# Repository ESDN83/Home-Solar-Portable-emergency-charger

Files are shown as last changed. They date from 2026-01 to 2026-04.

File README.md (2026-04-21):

<div align="center">

# ⚡ Home Solar Portable Emergency Charger 

**[🖼️ Bilder/Pictures](documentation/images.md)**

### Notstrom-Ladegerät für PV-Heimspeicher mittels Generator
### Emergency Charger for PV Home Battery Systems using Generator






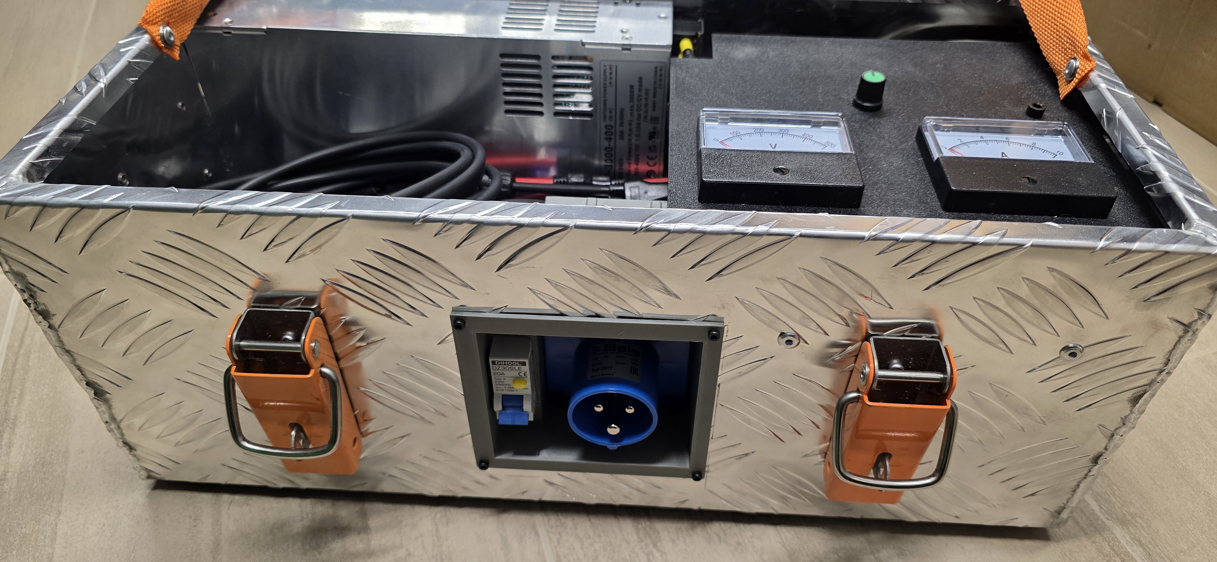
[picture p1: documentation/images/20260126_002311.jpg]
Project Photos


**[🇩🇪 Deutsch](#-deutsch)** | **[🇬🇧 English](#-english)**

</div>

---

## 📋 Table of Contents / Inhaltsverzeichnis

- [🇩🇪 Deutsch](#-deutsch)
  - [Überblick](#überblick)
  - [Das Problem](#das-problem)
  - [Die Lösung](#die-lösung)
  - [Hauptkomponenten](#-hauptkomponenten)
  - [Dokumentation](#-dokumentation)
- [🇬🇧 English](#-english)
  - [Overview](#overview)
  - [The Problem](#the-problem)
  - [The Solution](#the-solution)
  - [Main Components](#-main-components)
  - [Documentation](#-documentation)
- [⚠️ Safety / Sicherheit](#%EF%B8%8F-safety--sicherheit)
- [📚 References / Referenzen](#-references--referenzen)
- [📄 License / Lizenz](#-license--lizenz)

---

## 🇩🇪 Deutsch

### Überblick

Dieses Open-Source-Projekt beschreibt den Bau eines **portablen Notstrom-Ladegeräts** für PV-Heimspeicher-Systeme (E3/DC, Fronius, SMA, etc.). Das System ermöglicht es, einen handelsüblichen Generator zur Ladung des Hausspeichers zu nutzen, wenn das Stromnetz ausfällt.

### Das Problem

Viele moderne Heimspeicher-Systeme (wie E3/DC) verweigern das direkte Laden der Batterie über einen Generator am AC-Eingang aufgrund von:
- 🔴 Frequenzinstabilitäten des Generators
- 🔴 Netzqualität entspricht nicht den Anforderungen
- 🔴 Fehlende Grid-Code-Konformität

### Die Lösung

Statt den Generator direkt ans Hausnetz anzuschließen, nutzen wir einen **alternativen Ansatz**:

```
Generator (230V AC) 
    ↓
MeanWell CSP-3000-400 Netzteil
    ↓
DC-Spannung (350-400V, bis 7.5A)
    ↓
Sperrdioden (Anti-Backfeed)
    ↓
PV-Eingang (MPPT) des Wechselrichters
    ↓
Batterie wird geladen ✅
```

Das System **simuliert eine Solaranlage** und speist DC-Strom direkt in die MPPT-Tracker ein, wodurch der Heimspeicher geladen wird!

### 🔧 Hauptkomponenten

| Komponente | Spezifikation | Preis (ca.) |
|---|---|---|
| **MeanWell CSP-3000-400** | 400V DC, 7.5A, 3000W Schaltnetzteil | 350€ |
| **Gehäuse** | Alubox Werkzeugkiste Riffelblech (25L) | 90€ |
| **Sperrdiode** | Heschen MDK-55 (55A 1600V) | 11€ |
| **Messgeräte** | Analoges Voltmeter & Amperemeter | 17€ |
| **Sicherung** | 10A DC-Leistungsschutzschalter | 9€ |
| **Steuerung** | 0-10V Potentiometer-Modul | 15€ |

**Gesamtkosten**: ca. **550-600€** (ohne Generator)

### 📖 Dokumentation

| Dokument | Beschreibung |
|---|---|
| **[📦 Stückliste (PARTS.md)](documentation/PARTS.md)** | Vollständige Komponentenliste mit Amazon-Links |
| **[🔨 Aufbauanleitung (ASSEMBLY.md)](documentation/ASSEMBLY.md)** | Schritt-für-Schritt Montageanleitung mit Fotos |
| **[⚡ Schaltplan (SCHEMATICS.md)](documentation/SCHEMATICS.md)** | Detaillierte Verdrahtung und Anschlussdiagramme |
| **[🖨️ 3D-Druck Dateien](documentation/3d_files/)** | STL-Dateien für Gehäuse und Halterungen |

---

## 🇬🇧 English

### Overview

This open-source project describes the construction of a **portable emergency charger** for PV home battery systems (E3/DC, Fronius, SMA, etc.). The system enables the use of a standard generator to charge your home battery when the grid fails.

### The Problem

Many modern home battery systems (like E3/DC) refuse to charge directly from a generator via the AC input due to:
- 🔴 Generator frequency instability
- 🔴 Grid quality doesn't meet requirements
- 🔴 Missing grid code compliance

### The Solution

Instead of connecting the generator directly to the home grid, we use an **alternative approach**:

```
Generator (230V AC) 
    ↓
MeanWell CSP-3000-400 Power Supply
    ↓
DC Voltage (350-400V, up to 7.5A)
    ↓
Blocking Diodes (Anti-Backfeed)
    ↓
PV Input (MPPT) of Inverter
    ↓
Battery Charging ✅
```

The system **simulates a solar array** and feeds DC power directly into the MPPT trackers, allowing the home battery to charge!

### 🔧 Main Components

| Component | Specification | Price (approx.) |
|---|---|---|
| **MeanWell CSP-3000-400** | 400V DC, 7.5A, 3000W Power Supply | 350€ |
| **Housing** | Aluminum Checker Plate Tool Box (25L) | 90€ |
| **Blocking Diode** | Heschen MDK-55 (55A 1600V) | 11€ |
| **Indicators** | Analog Voltmeter & Ammeter | 17€ |
| **Protection** | 10A DC Miniature Circuit Breaker | 9€ |
| **Control** | 0-10V Potentiometer Module | 15€ |

**Total Cost**: approx. **550-600€** (excluding generator)

### 📖 Documentation

| Document | Description |
|---|---|
| **[📦 Parts List (PARTS.md)](documentation/PARTS.md)** | Complete component list with Amazon links |
| **[🔨 Assembly Guide (ASSEMBLY.md)](documentation/ASSEMBLY.md)** | Step-by-step assembly instructions with photos |
| **[⚡ Schematics (SCHEMATICS.md)](documentation/SCHEMATICS.md)** | Detailed wiring and connection diagrams |
| **[🖨️ 3D Print Files](documentation/3d_files/)** | STL files for housing and mounts |

---

## ⚠️ Safety / Sicherheit

<div align="center">

### ⚡ HOCHSPANNUNG - LEBENSGEFAHR / HIGH VOLTAGE - DANGER ⚡

</div>

**🇩🇪 Deutsch:**
- ⚠️ Dieses Projekt arbeitet mit **bis zu 400V DC** - tödliche Spannung!
- ⚠️ Arbeiten an Hochspannungssystemen nur durch **Elektrofachkräfte**
- ⚠️ Niemals unter Last stecken/trennen (Lichtbogengefahr!)
- ⚠️ Generator nur im **Außenbereich** betreiben (Abgasgefahr!)
- ⚠️ Verpolung zerstört sofort die Anlage
- ⚠️ Alle Schaltungen **doppelt prüfen** vor Inbetriebnahme

**🇬🇧 English:**
- ⚠️ This project involves **up to 400V DC** - lethal voltage!
- ⚠️ High voltage work only by **qualified electricians**
- ⚠️ Never connect/disconnect under load (arc flash hazard!)
- ⚠️ Generator operation **outdoors only** (exhaust hazard!)
- ⚠️ Reverse polarity will instantly destroy equipment
- ⚠️ **Double-check** all connections before operation

<div align="center">

**⚡ Nachbau auf eigene Gefahr! / Build at your own risk! ⚡**

</div>

---

## 📚 References / Referenzen

**🇩🇪 Ursprungsquelle / 🇬🇧 Original Source:**

Dieses Projekt basiert auf den Community-Diskussionen im Photovoltaikforum und der Zusammenfassung "Notstrom Zusammenfassung V3.pdf" von Mitgliedern des Forums.

This project is based on community discussions in the Photovoltaikforum and the summary "Notstrom Zusammenfassung V3.pdf" by forum members.

- 📖 **Forum Thread**: [Notstrom über Generator bei EFH mit E3/DC und Wärmepumpe](https://www.photovoltaikforum.com/thread/163745-notstrom-%C3%BCber-generator-bei-efh-mit-e3-dc-und-w%C3%A4rmepumpe/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)
- 📄 **Original PDF**: [Notstrom Zusammenfassung V3.pdf](https://www.photovoltaikforum.com/thread/163745-notstrom-%C3%BCber-generator-bei-efh-mit-e3-dc-und-w%C3%A4rmepumpe/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) - Download im Forum verfügbar / Download available in forum
- 👥 **Credits**: Arno Waldmann, Roland B., und alle Forumsteilnehmer / and all forum participants

---

## 📄 License / Lizenz

<div align="center">

[][cc-by-nc-sa]

Dieses Werk ist lizenziert unter einer [Creative Commons Attribution-NonCommercial-ShareAlike 4.0 International License][cc-by-nc-sa].

This work is licensed under a [Creative Commons Attribution-NonCommercial-ShareAlike 4.0 International License][cc-by-nc-sa].

[cc-by-nc-sa]: http://creativecommons.org/licenses/by-nc-sa/4.0/
[cc-by-nc-sa-shield]: https://img.shields.io/badge/License-CC%20BY--NC--SA%204.0-lightgrey.svg

**Das bedeutet / This means:**
- ✅ Teilen / Share — copy and redistribute
- ✅ Anpassen / Adapt — remix, transform, build upon
- ⚠️ Namensnennung / Attribution required
- ⚠️ Weitergabe unter gleichen Bedingungen / ShareAlike
- 🚫 **KEINE kommerzielle Nutzung / NO commercial use**

</div>

---

<div align="center">

### 🌟 Wenn dir dieses Projekt gefällt, gib ihm einen Star! / If you like this project, give it a star! 🌟

**Made with ❤️ by the DIY Solar Community**

</div>

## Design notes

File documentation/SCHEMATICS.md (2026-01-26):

# ⚡ Schaltplan & Anschlüsse / Schematics & Connections

<div align="center">

**Detaillierte Verdrahtung und elektrische Anschlüsse**  
**Detailed Wiring and Electrical Connections**

</div>

---

## 📊 Systemübersicht / System Overview

### Visuelles Blockschaltbild / Visual Block Diagram

<div align="center">

System Overview

</div>

<details>
<summary>🔍 Mermaid Diagramm anzeigen / Show Mermaid Diagram</summary>

```mermaid
graph LR
    subgraph AC_Input [AC Eingang]
        Gen[🔌 Generator] --> CEE[CEE Stecker]
        CEE --> RCBO[FI/LS Schutzschalter]
    end

    subgraph Power_Unit [Ladegerät Gerät]
        RCBO --> MW[📦 MeanWell CSP-3000]
        
        subgraph DC_Output_Chain [DC Ausgangskette]
            MW --> Diode[🔒 Sperrdiode<br/>MDK-55]
            Diode --> Volt[📟 Voltmeter]
            Volt --> Amp[📊 Amperemeter]
            Amp --> Fuse[⚡ DC Sicherung<br/>10A Automat]
        end
    end

    subgraph PV_Connection [PV Anschluss]
        Fuse --> MC4[MC4 Buchse]
        MC4 --> WR[🏠 Wechselrichter<br/>MPPT Eingang]
    end

    Poti[🎛️ Potentiometer] -.->|CN2| MW

    style Gen fill:#fff,stroke:#ff9800,stroke-width:2px,color:#000
    style MW fill:#fff,stroke:#2196f3,stroke-width:2px,color:#000
    style Diode fill:#fff,stroke:#f44336,stroke-width:2px,color:#000
    style Fuse fill:#fff,stroke:#4caf50,stroke-width:2px,color:#000
    style WR fill:#fff,stroke:#9c27b0,stroke-width:2px,color:#000
    style RCBO fill:#fff,stroke:#607d8b,stroke-width:2px,color:#000
```

</details>

### Signalfluss / Signal Flow

| Phase | Komponente | Spannung | Beschreibung |
|---|---|---|---|
| 1️⃣ | Generator | 230V AC | Stromquelle |
| 2️⃣ | CEE → RCBO | 230V AC | Schutz & Eingang |
| 3️⃣ | MeanWell PSU | AC→DC | Wandlung auf 350-400V DC |
| 4️⃣ | DC Kette | 350-400V DC | Schutz & Monitoring |
| 5️⃣ | MC4 → MPPT | 350-400V DC | Ausgang zum Wechselrichter |

---

## ⚡ Vollständiger Schaltplan / Detailed Wiring

### Visueller Verdrahtungsplan / Visual Wiring Diagram

<div align="center">

Detailed Wiring Diagram

</div>

### Reihenfolge der DC-Komponenten (Plus-Pol) / DC Component Order (Positive Rail)

Die korrekte Reihenfolge ist **kritisch** für die Sicherheit! / The correct order is **critical** for safety!

| Nr. | Komponente | Spezifikation | Funktion |
|-----|---|---|---|
| 1️⃣ | **MeanWell CSP-3000-400 (+V)** | 400V DC, 7.5A | DC-Spannungsquelle |
| 2️⃣ | **Sperrdiode (MDK-55)** | 55A 1600V | 🔴 Verhindert Rückstrom vom PV-System |
| 3️⃣ | **Voltmeter** | 0-500V DC analog | Anzeige der Ausgangsspannung |
| 4️⃣ | **Amperemeter** | 0-10A DC analog | Anzeige des Ladestroms |
| 5️⃣ | **DC Sicherung** | 10A 500V DC | Überlast-/Kurzschlussschutz |
| 6️⃣ | **MC4 Buchse (+)** | Solar-Standard | Ausgang zum Wechselrichter |

### Minus-Pol (-V) / Negative Rail

```
MeanWell (-V) ─────────────────────────────────> MC4 Buchse (-)
              │                                        │
              └──────── Direkt / Direct ───────────────┘
```

*Der Minus-Pol wird direkt vom Netzteil zur MC4-Buchse geführt - keine Unterbrechung!*  
*The negative rail goes directly from PSU to MC4 connector - no interruption!*

### Verkabelungsspezifikationen / Wiring Specifications

| Leitung | Querschnitt | Typ | Farbe |
|---|---|-----|---|
| DC Plus (+) | 6mm² | Solarkabel | 🔴 Rot/Red |
| DC Minus (-) | 6mm² | Solarkabel | ⚫ Schwarz/Black |
| Steuerung | 0.5-1mm² | Flexibel | 🟡 Gelb/Yellow |
| AC Eingang | 2.5mm² | H07RN-F | Braun/Blau/Grün-Gelb |

---

## 🎛️ Steuerung (CN2 Port) / Control (CN2 Port)

Die Steuerung erfolgt über ein **0-10V Potentiometer-Modul**, welches an den CN2 Port des MeanWell Netzteils angeschlossen wird.

### MeanWell CN2 Pinbelegung / Pin Assignment

| Pin | Bezeichnung | Funktion | Verbindung |
|-----|---|---|---|
| **Pin 1** | +12V | Stromversorgung für Potentiometer | Modul (+) Eingang |
| **Pin 2** | -12V (GND) | Masse für Potentiometer | Modul (-) Eingang |
| **Pin 5** | V_ADJ | Steuerspannung 0-10V | Modul Signal Ausgang |
| **Pin 6** | -V_ADJ | Signal Masse | Modul Signal (-) |

### Schaltschema / Wiring Schematic

```
┌─────────────────┐           ┌──────────────────┐
│   MeanWell      │           │  Potentiometer   │
│   CN2 Port      │           │     Modul        │
│                 │           │                  │
│  Pin 1 (+12V) ──┼───────────┼── (+) Eingang    │
│                 │           │                  │
│  Pin 2 (-12V) ──┼───────────┼── (-) Eingang    │
│                 │           │                  │
│  Pin 5 (V_ADJ)──┼───────────┼── Signal (+)     │
│                 │           │                  │
│  Pin 6 (-V_ADJ)─┼───────────┼── Signal (-)     │
└─────────────────┘           └──────────────────┘
```

> 📷 **Offizielle Dokumentation / Official Documentation:**
> 
> MeanWell CN2 Pinout
> 
> 📄 [MeanWell CSP-3000 Datenblatt / Datasheet (PDF)](https://www.meanwell.com/Upload/PDF/CSP-3000/CSP-3000-SPEC.PDF)

### Spannungseinstellung / Voltage Adjustment

> ⚠️ **Constant Current Mode (CC)**: Das Netzteil ist auf konstanten Strom konfiguriert (CN1).
> Die Spannung variiert je nach Last!

| Poti-Stellung | Steuerspannung | Ohne Last | Mit Last | Ladestrom (ca.) |
|---|---|---|---|---|
| Minimum | 0V | ~350V DC | - | 0A |
| Mitte | 5V | ~350V DC | ~380V DC | ~4A |
| Maximum | 10V | ~350V DC | ~400V DC | 7.5A |

**Erklärung / Explanation:**
- **Ohne Last (No Load)**: Spannung bleibt bei ~350V (Leerlauf)
- **Mit Last (With Load)**: Spannung steigt auf bis zu 400V (Constant Current Regelung)

---

## ⚠️ Sicherheitshinweise / Safety Notes

<div align="center">

### ⚡ HOCHSPANNUNG - LEBENSGEFAHR / HIGH VOLTAGE - DANGER ⚡

</div>

### Kritische Punkte / Critical Points

| Risiko | Maßnahme | Priorität |
|---|---|---|
| 🔴 **Sperrdiode** | MUSS als erstes Bauteil nach dem Netzteil sitzen! | ⚠️ KRITISCH |
| 🔴 **Verpolung** | Alle Anschlüsse doppelt prüfen vor Inbetriebnahme | ⚠️ KRITISCH |
| 🟠 **Lichtbogen** | Niemals unter Last stecken/trennen | WICHTIG |
| 🟠 **Kurzschluss** | DC-Automat als Lasttrennschalter verwenden | WICHTIG |
| 🟡 **Wärme** | Sperrdiode benötigt Kühlung (Metallgehäuse) | BEACHTEN |

### Checkliste vor Inbetriebnahme / Pre-Operation Checklist

- [ ] Alle Schraubverbindungen fest angezogen
- [ ] Kabelquerschnitte entsprechen den Spezifikationen
- [ ] Sperrdiode richtig gepolt (Kathode Richtung MC4)
- [ ] Keine blanken Leitungen oder Kurzschlussgefahr
- [ ] RCBO funktioniert (Testknopf drücken)
- [ ] Voltmeter zeigt Spannung erst NACH Einschalten
- [ ] Potentiometer auf Minimum vor dem Start

---

## 📸 Bildergalerie / Photo Gallery

<details>
<summary>🖼️ Interne Verdrahtung anzeigen / Show Internal Wiring</summary>

| Beschreibung | Bild |
|---|---|
| Gesamtaufbau | Assembly |
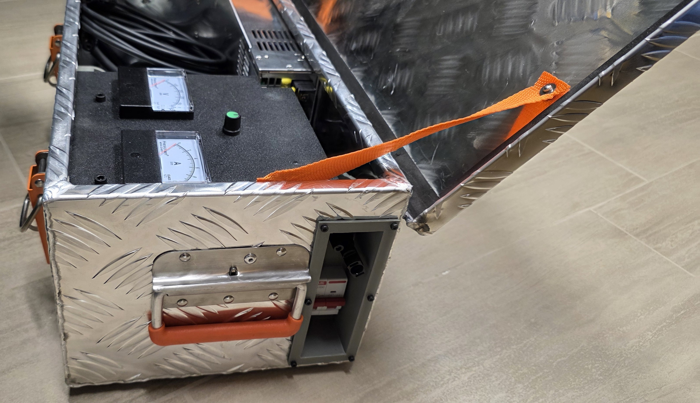
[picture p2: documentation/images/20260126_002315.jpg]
DC Wiring
| DC-Verkabelung |  |
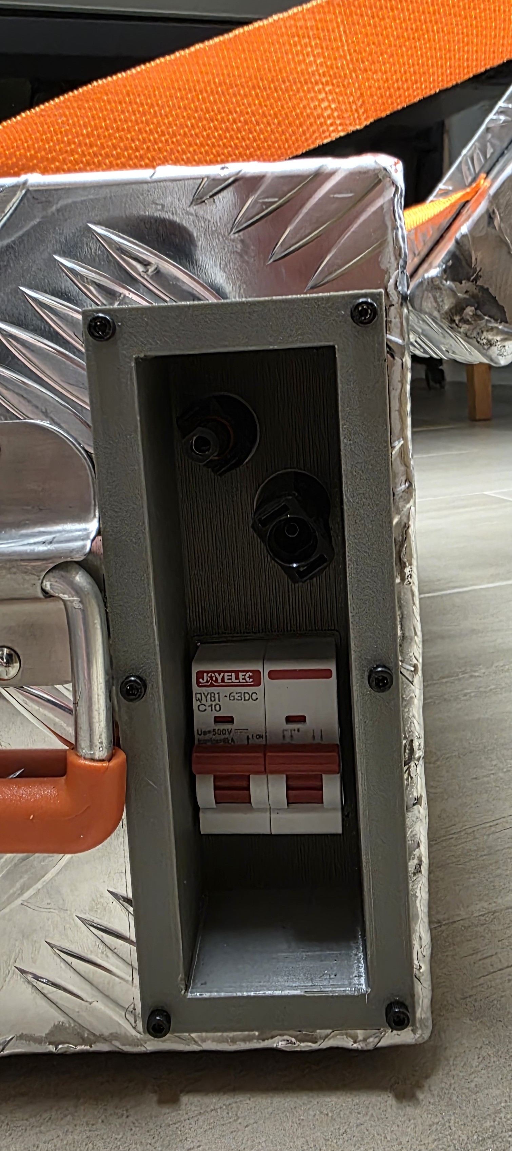
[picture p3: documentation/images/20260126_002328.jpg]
Control
| Steuereinheit |  |

</details>

---

**[◀ Zurück zur Aufbauanleitung / Back to Assembly](ASSEMBLY.md)** | **[🏠 Zurück zur Hauptseite / Back to Main](../README.md)**

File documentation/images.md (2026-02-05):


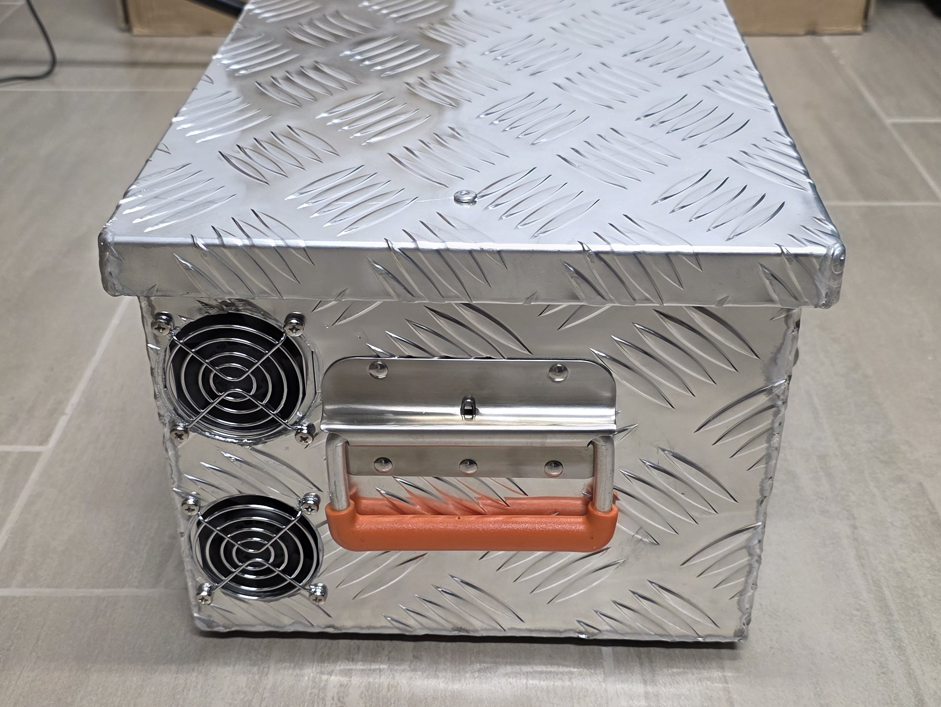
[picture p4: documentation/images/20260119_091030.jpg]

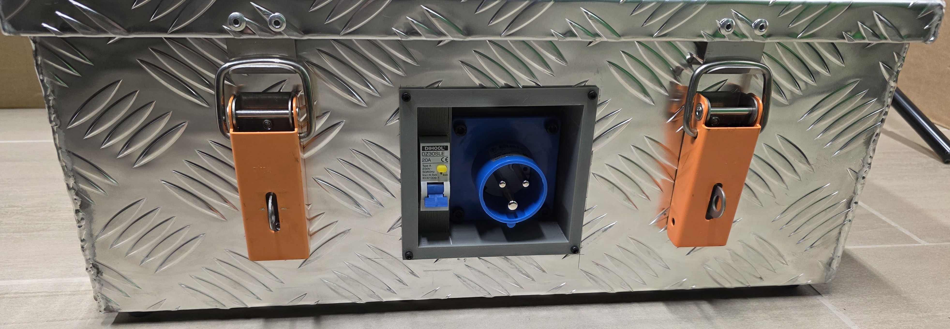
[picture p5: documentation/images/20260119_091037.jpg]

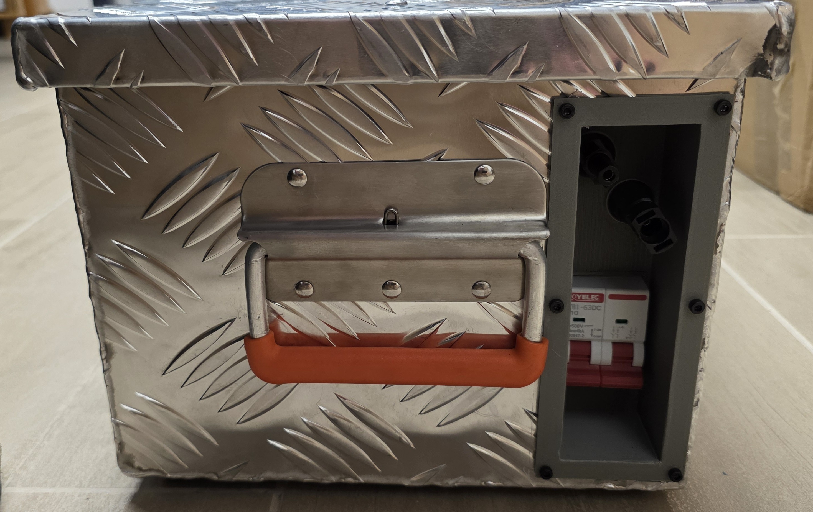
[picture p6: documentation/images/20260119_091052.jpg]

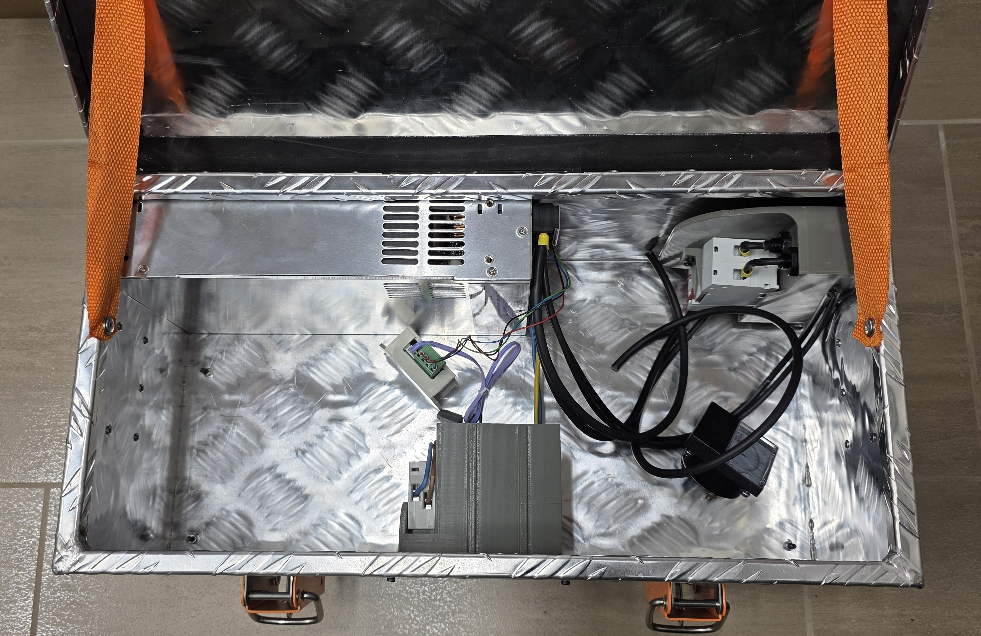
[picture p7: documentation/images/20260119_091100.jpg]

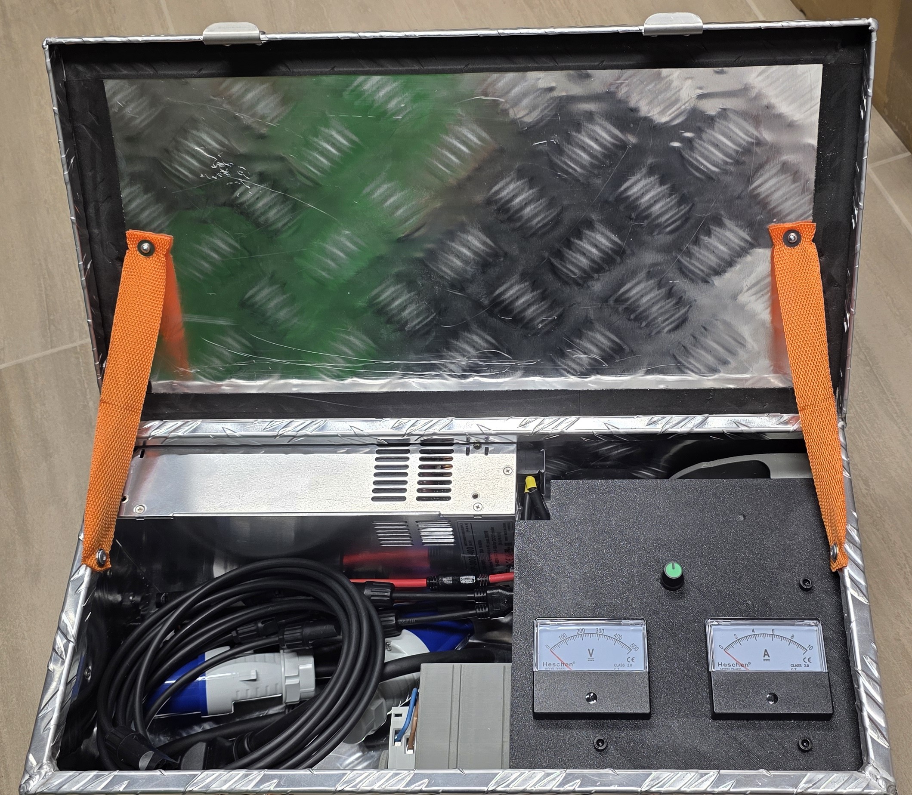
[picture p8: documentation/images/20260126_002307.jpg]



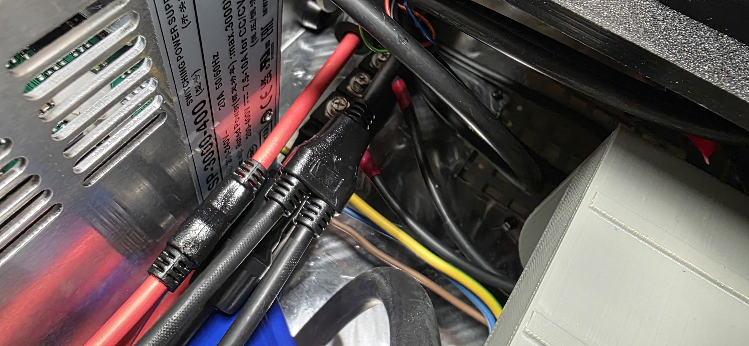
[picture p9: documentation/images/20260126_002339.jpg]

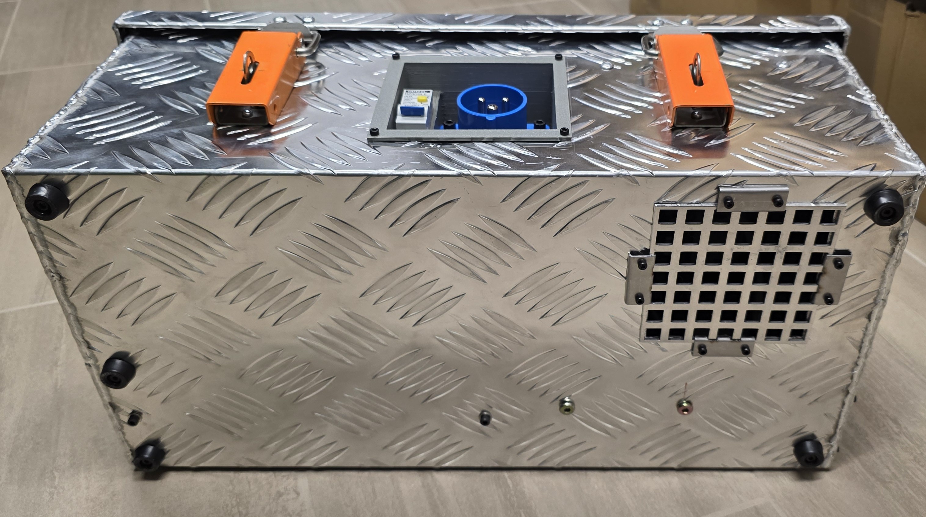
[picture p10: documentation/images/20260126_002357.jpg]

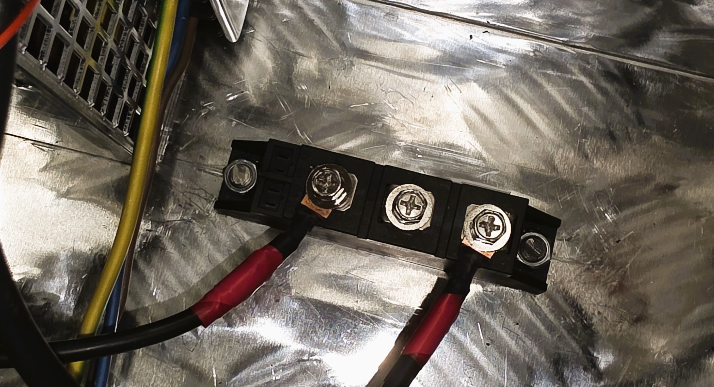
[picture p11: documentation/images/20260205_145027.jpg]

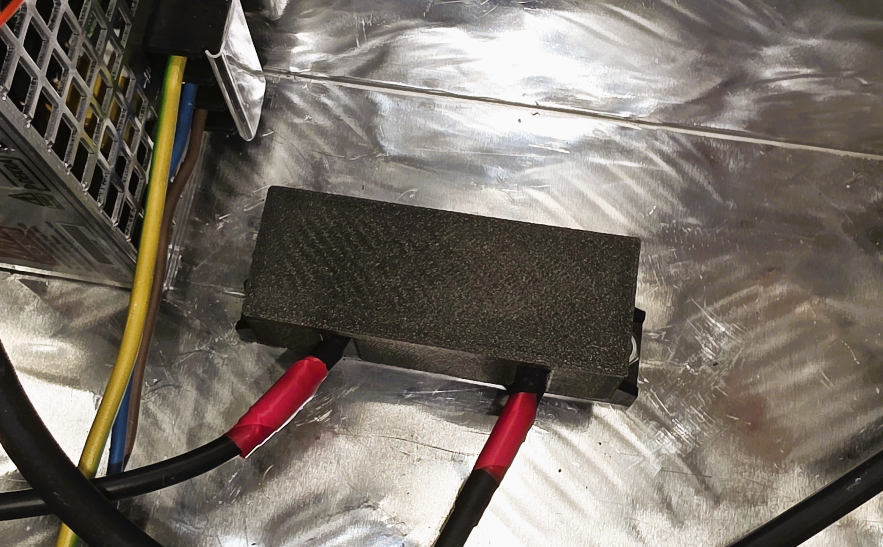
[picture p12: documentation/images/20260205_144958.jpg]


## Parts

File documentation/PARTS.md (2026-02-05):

# 📦 Stückliste / Parts List

<div align="center">

**Vollständige Komponentenliste für das Notstrom-Ladegerät**  
**Complete Component List for the Emergency Charger**

</div>

---

## 🔋 Hauptkomponenten / Main Components

### 1. Netzteil / Power Supply Unit

| Artikel | Hersteller | Modell | Spezifikation | Preis | Link |
|---|---|---|---|---|---|
| **Schaltnetzteil** | MeanWell | CSP-3000-400 | 400V DC, 7.5A, 3000W | 349,95€ | [Voelkner](https://www.voelkner.de/products/1412939/MEAN-WELL-CSP-3000-400-Schaltnetzteil-400-V-DC-7.5A-3000W.html) |

---

### 2. Steuerung & Anzeige / Control & Display

| Artikel | Beschreibung | Preis | Link |
|---|---|---|---|
| **Potentiometer Modul** | 0-10V Potentiometer zur Spannungsregelung | 15,39€ | [Amazon B0CFYQY5YW](https://www.amazon.de/dp/B0CFYQY5YW) |
| **Voltmeter** | Analoges Einbau-Voltmeter DC 0-500V | 8,49€ | [Amazon B06Y2HDS1X](https://www.amazon.de/dp/B06Y2HDS1X) |
| **Amperemeter** | Analoges Einbau-Amperemeter DC 10A | 8,69€ | [Amazon B07G35GMS6](https://www.amazon.de/dp/B07G35GMS6) |
| **Steuerkabel** | 8-pol Kabelkit für MeanWell CN1/CN2 | 19,90€ | [Henri.de](https://www.henri.de/Stromversorgung/Schaltnetzteile/Kabelsaetze/8748/Kabelkit-SYNCKABEL-8pol-Steuerleitung-fuer-MeanWell-CN1-CN2-CN100-8pol-Stecker-zur-Netzteile-Se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) |

---

### 3. Sicherheit / Safety

| Komponente | Spezifikation | Preis | Link |
|---|---|---|---|
| **Sperrdiode** | Heschen MDK-55 (55A 1600V) Antireverse-Gleichrichter | 10,89€ | [Amazon B0C33MKF6R](https://www.amazon.de/dp/B0C33MKF6R) |
| **Sicherung** | 10A DC-Leistungsschutzschalter (2-polig, 500V) | 8,29€ | [Amazon B0DXKYR1FZ](https://www.amazon.de/dp/B0DXKYR1FZ) |
| **RCBO** | DIHOOL FI/LS Schutzschalter 20A 30mA (AC-Seite) | 19,88€ | [Amazon B0DZN5TVRW](https://www.amazon.de/dp/B0DZN5TVRW) |

---

### 4. Gehäuse & Montage / Housing & Mounting

| Artikel | Beschreibung | Preis | Link |
|---|---|---|---|
| **Gehäuse** | Alubox Riffelblech Werkzeugkiste 25 Liter | 89,95€ | [Amazon B0FFT9QJZR](https://www.amazon.de/dp/B0FFT9QJZR) |
| **CEE Anbaustecker** | as-Schwabe CEE Camping Stecker (für Gehäuseeinbau) | 6,34€ | [Amazon B0CDWTM1FH](https://www.amazon.de/dp/B0CDWTM1FH) |
| **Lochblech** | Alu QG10-15 (für die Montage im Gehäuse) | 8,30€ | [Amazon B077LZMKLQ](https://www.amazon.de/dp/B077LZMKLQ) |
| **Gummifüße** | Adam Hall Gummifuß Set (4 Stück) | 1,84€ | [Amazon B00SJFDI16](https://www.amazon.de/dp/B00SJFDI16) |

---

### 5. Kleinteile & Adapter / Small Parts & Adapters

| Artikel | Beschreibung | Preis | Link |
|---|---|---|---|
| **Ringkabelschuhe** | 6mm² M5 Kupfer (20 Stück) | 6,99€ | [Amazon B0DN6DRGG2](https://www.amazon.de/dp/B0DN6DRGG2) |
| **PV Stecker Set** | 12 Paar MC4-kompatible Stecker | 9,99€ | [Amazon B0C8NNLCDH](https://www.amazon.de/dp/B0C8NNLCDH) |
| **MC4 Einbau** | MC4 Gehäusestecker (Paar) | 4,00€ | [Amazon B0DJ7J3V5K](https://www.amazon.de/dp/B0DJ7J3V5K) |
| **CEE Adapter 1** | CEE Stecker auf Schuko Kupplung | 9,59€ | [Amazon B0D32VCTH4](https://www.amazon.de/dp/B0D32VCTH4) |
| **CEE Adapter 2** | Schuko Stecker auf CEE Kupplung | 9,49€ | [Amazon B0DXCDVQ6L](https://www.amazon.de/dp/B0DXCDVQ6L) |

---

## 🖨️ 3D-Druck Teile / 3D Printed Parts

Alle STL-Dateien sind im Ordner [`3d_files/`](3d_files/) verfügbar. Diese dienen zur stabilen Montage der Komponenten in der Alubox.

### 1. DIN Rail Mount - Hutschiene für Sicherungen
🔗 [Auf GitHub ansehen](https://github.com/ESDN83/Home-Solar-Portable-emergency-charger/blob/main/documentation/3d_files/DIN_RAIL_Mount_lying.stl)
- **Beschreibung**: Halterung für die beiden Sicherungsautomaten (DC-Sicherung und FI/LS).

### 2. CEE Connector Mount - CEE-Stecker Halterung
🔗 [Auf GitHub ansehen](https://github.com/ESDN83/Home-Solar-Portable-emergency-charger/blob/main/documentation/3d_files/Solar-Box-CEE-Stecker_v3.stl)
- **Beschreibung**: Halterung für den CEE-Eingangsstecker am Alugehäuse.

### 3. Solar Connector Mount - MC4 Halterung
🔗 [Auf GitHub ansehen](https://github.com/ESDN83/Home-Solar-Portable-emergency-charger/blob/main/documentation/3d_files/Solar-Box-Solar.Stecker_V2.stl)
- **Beschreibung**: Halterung für die MC4-Ausgangsbuchsen.

### 4. Deckplatte - Abdeckung
🔗 [Auf GitHub ansehen](https://github.com/ESDN83/Home-Solar-Portable-emergency-charger/blob/main/documentation/3d_files/Deckplatte_Solar-charge.stl)
- **Beschreibung**: Obere Abdeckplatte für die interne Montageeinheit.

### 5. Heschen MDK55 Cap
🔗 [Auf GitHub ansehen](https://github.com/ESDN83/Home-Solar-Portable-emergency-charger/blob/main/documentation/3d_files/Heschen%20MDK55%20Cap.stl)
- **Beschreibung**: Abdeckung für die Heschen Diode um Berührung zu verhindern.

---

## 💰 Kostenzusammenfassung / Cost Summary

| Kategorie | Kosten (ca.) |
|---|---|
| MeanWell CSP-3000-400 | 350€ |
| Steuerung & Anzeige | 55€ |
| Sicherheit | 40€ |
| Gehäuse & Montage | 105€ |
| Kleinteile & Adapter | 40€ |
| **Gesamt** | **~590€** |

---

**[◀ Zurück zur Hauptseite](../README.md)** | **[Weiter zur Aufbauanleitung ▶](ASSEMBLY.md)**

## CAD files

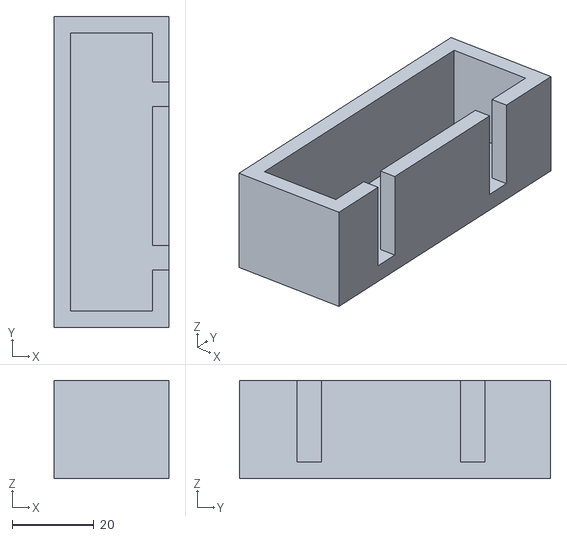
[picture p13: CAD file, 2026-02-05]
documentation/3d_files/Heschen MDK55 Cap.stl
28.0 x 76.0 x 24.0

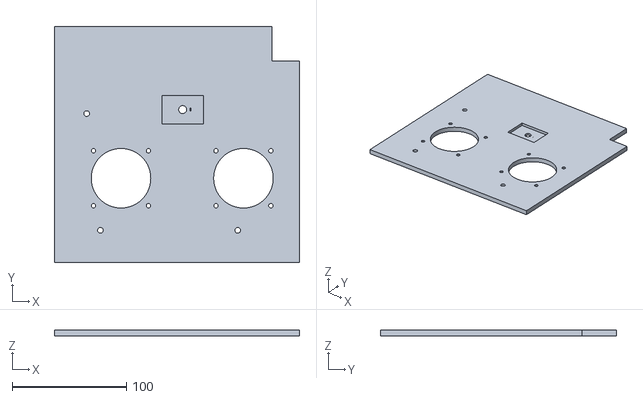
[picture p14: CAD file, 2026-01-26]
documentation/3d_files/Deckplatte_Solar-charge.stl
214.1 x 206.0 x 5.00

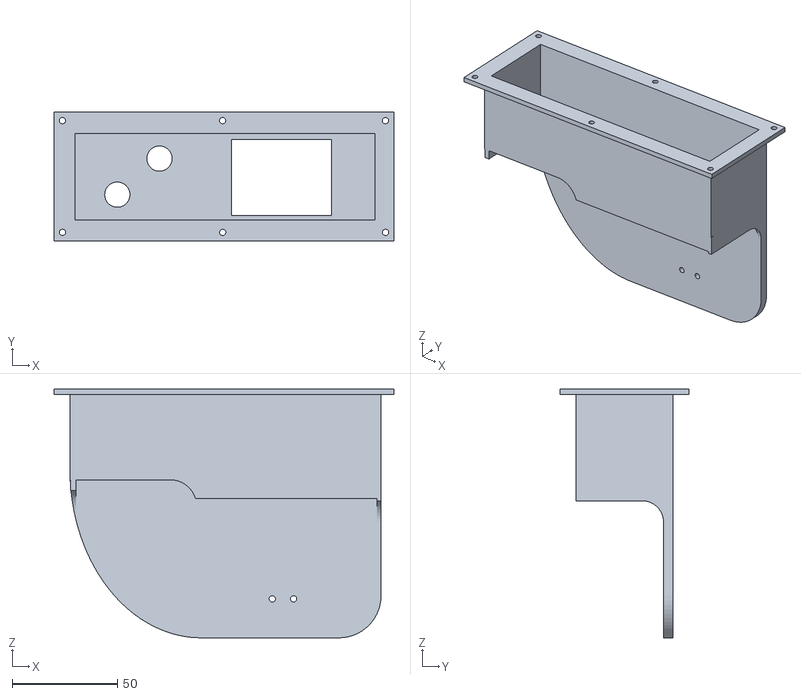
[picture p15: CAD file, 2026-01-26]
documentation/3d_files/Solar-Box-Solar.Stecker_V2.stl
161.3 x 61.0 x 118.0

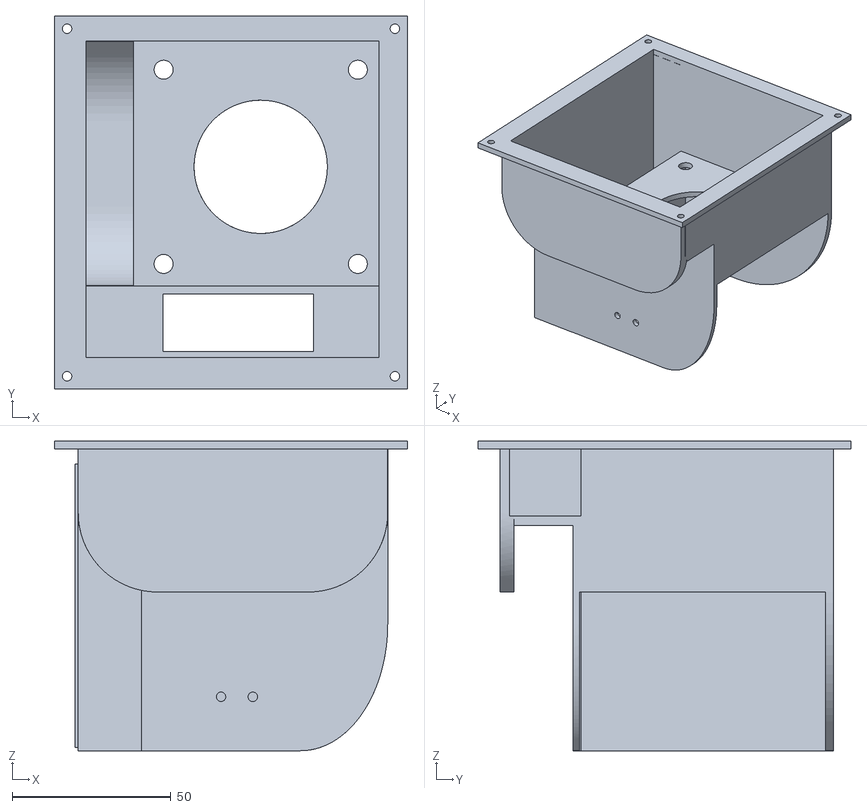
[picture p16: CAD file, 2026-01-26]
documentation/3d_files/Solar-Box-CEE-Stecker_v3.stl
111.3 x 117.5 x 97.5

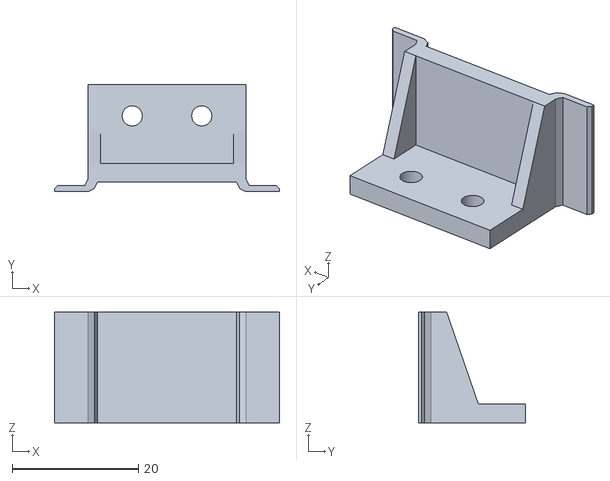
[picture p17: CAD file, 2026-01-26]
documentation/3d_files/DIN_RAIL_Mount_lying.stl
35.6 x 17.0 x 17.5

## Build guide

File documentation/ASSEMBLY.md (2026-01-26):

# 🔨 Aufbauanleitung / Assembly Instructions

<div align="center">

**Schritt-für-Schritt Anleitung zum Bau des Notstrom-Ladegeräts in der Alubox**  
**Step-by-Step Guide to Build the Emergency Charger using an Aluminum Box**

</div>

---

## 📋 Voraussetzungen / Prerequisites

- ✅ Alle Komponenten aus der [Stückliste](PARTS.md) (inkl. Alubox)
- ✅ 3D-Drucker für interne Halterungen
- ✅ Metallbohrer, Stichsäge oder Dremel (für Ausschnitte in der Alubox)
- ✅ Crimpwerkzeug für Ringkabelschuhe und MC4 Stecker
- ✅ **Elektrofachkraft empfohlen!** (400V DC ist lebensgefährlich)

---

## 📦 Schritt 1: Gehäuse vorbereiten / Step 1: Prepare Housing (Alubox)

Anstatt eines komplett gedruckten Gehäuses verwenden wir eine robuste **Riffelblech-Alubox (25L)**.

1. **Ausschnitte für Instrumente**:
   - Analoge Anzeigen für **Volt** und **Ampere** im Deckel oder an der Front positionieren.
   - Ausschnitte markieren und mit Stichsäge/Dremel vorsichtig ausschneiden.
2. **Potentiometer & Schalter**:
   - Bohrung für das Potentiometer-Modul setzen.
   - Einbauplatz für den DC-Sicherungsautomaten vorsehen (Hutschienen-Stück in der Box).
3. **Anschlüsse**:
   - Ausschnitte für den **CEE-Anbaustecker** (AC Eingang) und die **MC4-Buchsen** (DC Ausgang) bohren.

---

## 🖨️ Schritt 2: Interne Halterungen (3D-Druck) / Step 2: Internal Mounts

Die 3D-gedruckten Teile dienen zur stabilen Befestigung der Komponenten auf dem Lochblech innerhalb der Alubox.

- **DIN_RAIL_Mount**: Zur Montage des MeanWell Netzteils auf einer Hutschiene.
- **Stecker-Halterungen**: Zur zusätzlichen Fixierung der Buchsen.

---

## ⚡ Schritt 3: Mechanische Montage / Step 3: Mechanical Assembly

1. **Lochblech einpassen**: Das Alu-Lochblech dient als Montageplatte am Boden der Box.
2. **Netzteil fixieren**: Das MeanWell Netzteil mit den 3D-Halterungen auf das Lochblech schrauben.
3. **Sperrdiode montieren**: Die **MDK-55 Diode** muss fest auf einer metallischen Oberfläche (Kühlkörper oder Gehäusewand) montiert werden, da sie im Betrieb warm wird.

---

## 🔌 Schritt 4: Verkabelung / Step 4: Wiring

Folgen Sie exakt dieser Reihenfolge für den Plus-Pol:

```
MeanWell (+) ➔ Sperrdiode (MDK-55) ➔ Voltmeter ➔ Amperemeter ➔ DC-Sicherung ➔ MC4-Buchse (+)
```

1. **AC-Seite**: CEE-Anbaustecker -> FI/LS Schutzschalter (RCBO) -> MeanWell AC-Eingang.
2. **DC-Seite**: 
   - Verwenden Sie **6mm² Solarkabel** für die Hauptleitung.
   - Alle Verbindungen mit Ringkabelschuhen (M5) fest verschrauben.
3. **Messgeräte**: Voltmeter parallel, Amperemeter in Reihe schalten.

---

## 🎛️ Schritt 5: Steuerung / Step 5: Control

Das Potentiometer-Modul wird mit dem 8-poligen Sync-Kabel verbunden an CN2 -> https://github.com/ESDN83/Home-Solar-Portable-emergency-charger/blob/main/documentation/SCHEMATICS.md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

1. **Pin 1 (+12V)** an Moduleingang (+).
2. **Pin 2 (-12V)** an Moduleingang (-).
3. **Pin 5 (V_ADJ)** an Modulausgang (Signal).
4. **Pin 6 (-V_ADJ )** an Modulausgang (Signal -).

Damit lässt sich der Ladestrom regeln.

---

## 🧪 Schritt 6: Test & Inbetriebnahme / Step 6: Testing

1. **Sichtprüfung**: Alle Kontakte fest? Keine Kurzschlüsse am Alugehäuse?
2. **Leerlauftest**: Generator an -> CEE einstecken -> Strom am Potentiometer regeln.
3. **Anzeige**: Prüfen, ob das Voltmeter/Ampermeter die korrekte Spannung/Strom anzeigt.
4. **Lasttest**: Erst wenn alles stabil ist, an den Wechselrichter anschließen.

---

**[◀ Zurück zur Stückliste](PARTS.md)** | **[Weiter zum Schaltplan ▶](SCHEMATICS.md)**

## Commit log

2026-01-26 Initial commit: Complete documentation for Home Solar Portable Emergency Charger
    - Professional README with badges and bilingual content (DE/EN)
    - Detailed parts list with component specifications
    - Step-by-step assembly instructions with safety warnings
    - Comprehensive schematics with Mermaid diagrams
    - 3D print files (STL) for housing components
    - Project photos and gallery
    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
    [DIN_RAIL_Mount_lying.stl, Deckplatte_Solar-charge.stl, Solar-Box-CEE-Stecker_v3.stl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]
2026-01-26 docs: Add link to original PDF in forum and remove local PDF copy
    - Added direct download link to 'Notstrom Zusammenfassung V3.pdf' in forum thread
    - Removed local PDF copy (2.4 MB) as documentation is now comprehensive
    - All relevant information from PDF is covered in PARTS.md, ASSEMBLY.md, and SCHEMATICS.md
    - Users can now access the original source directly from the forum
2026-01-26 docs: Add 3D preview links for STL files in PARTS.md
    - Added direct GitHub links to view STL files as interactive 3D models
    - Reorganized 3D print section with individual descriptions for each part
    - Added file sizes and detailed descriptions
    - Users can now view 3D previews directly on GitHub before downloading
2026-01-26 docs: Comprehensive update based on actual hardware (teile.xlsx)
    - Corrected all product descriptions in PARTS.md
    - Updated Schematics to reflect actual wiring order: PSU -> Diode (MDK-55) -> Voltmeter -> Ammeter -> Fuse
    - Changed housing from 3D-printed box to Aluminum Tool Box (25L)
    - Updated Assembly guide for mechanical work on Aluminum box
    - Fixed unreadable colors in Mermaid diagrams
    - Included 0-10V Potentiometer module for control
    [teile.xlsx]
2026-01-26 docs: Fix DIN Rail description and add missing STL files to PARTS.md
2026-01-26 docs: Remove teile.xlsx from tracking and add to .gitignore
    [teile.xlsx]
2026-01-26 📊 Add visual SVG diagrams and improve SCHEMATICS documentation
    - Add system-overview.svg: Color-coded block diagram showing complete system flow
    - Add detailed-wiring.svg: Detailed wiring schematic with numbered steps and CN2 pinout
    - Update SCHEMATICS.md: Add SVG images, fix CN2 pinout (Pin 1,2,5,6), add tables and checklists
    - Add DOCUMENTATION_IMPROVEMENTS.md: Summary of changes and suggestions for future improvements
2026-01-26 🔧 Fix voltmeter wiring diagram and voltage adjustment table
    - Voltmeter: Show correct PARALLEL connection (needs + AND - wires)
    - Voltmeter: Add dashed line showing negative connection to rail
    - Voltage table: Fix to show Constant Current mode behavior
    - No load: ~350V DC
    - With load: up to ~400V DC
    - Legend: Add explanation that voltmeter needs both + and - connection
    - Legend: Add explanation that amperemeter is in series (+ only)
2026-11-05 docs: correct DC wiring diagram, negative runs through 2-pole breaker
    The diagram and text showed the negative rail going directly to the MC4
    socket, but the DC breaker is 2-pole and disconnects both rails.
    Redraw detailed-wiring.svg with both poles, the voltmeter in parallel
    and the diode in forward direction. Document the earthing via the PSU
    case screwed to the box and the MDK-55 terminals in use.
2026-11-05 docs: fix swapped CN2 pin 1 and 2 for potentiometer supply
    Per the Mean Well CSP-3000 datasheet, CN2 pin 1 is 12V AUXG (GND) and
    pin 2 is 12V AUX+. The docs had them reversed, which would connect the
    potentiometer module with reversed polarity.
    Correct SCHEMATICS.md, ASSEMBLY.md and detailed-wiring.svg, and add a
    note asking anyone who wired from the old version to check polarity.
    Reported in the photovoltaikforum.com thread on emergency power via
    generator.
2026-11-05 docs: add multimeter check before connecting potentiometer module
    Measure about +12V between CN2 pin 1 (GND) and pin 2 (+12V) at the cable
    end before connecting the module, to catch swapped wires.
2026-11-05 docs: warn about 500V limit of voltmeter and DC breaker
    The PSU delivers at most 400V, but the PV side can supply more. The
    voltmeter and DC breaker are rated to 500V DC and see the MC4 socket
    voltage when the breaker is closed.
    Add the limit to the safety notes, the pre-operation checklist and the
    README, including cold-weather open-circuit voltage.
2026-11-05 docs: correct 500V warning for splitter diode setup
    The box is connected in parallel with a PV string through a splitter
    with a diode, so PV voltage does not reach it when wired correctly. The
    previous warning implied the voltmeter and breaker normally see the
    string voltage.
    State that the 500V limit only matters if that diode is missing,
    defective or misplaced, and that voltage on the voltmeter with the PSU
    off indicates this fault.
2026-11-05 docs: add Y plug with diode for parallel PV string operation
    The box connects in parallel with a PV string through an MC4 Y plug with
    a diode on the positive side, ahead of the cable to the box. Add it to
    the wiring diagram, Mermaid chart, component order, assembly steps and
    parts list, without a specific model.
    That diode blocks PV voltage from the box only, so warn about reverse
    current from the box into the string when the string voltage is lower.
2026-11-11 docs: add community cover caps (ammeter, voltmeter, Heschen V2/V3) by ttoommeekk

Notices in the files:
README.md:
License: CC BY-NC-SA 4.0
